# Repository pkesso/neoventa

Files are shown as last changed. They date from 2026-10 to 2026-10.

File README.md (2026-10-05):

# Neoventa — Venta Overdrive PCB

A PCB for the Venta Overdrive, a clone of the PE-12 overdrive by Elektronika. The board is 50 × 54 mm, has 2 layers and fits a Hammond 1590N1 (125B) enclosure. SMD parts go on the bottom side and are assembled by JLCPCB. Pots and the wire pads go on the top side and are soldered by hand.

The schematic and the board are generated by Python scripts from a single circuit description (`tools/circuit2.py`). The layout was not drawn by hand in KiCad.

## Status

**Done**
- The schematic was traced from the stripboard layout and checked against the factory schematic of the PE-12 (`pics/moar/1.png`, `2.png`).
- The ngspice simulation gives about ±0.25 V at the output for a 100 mV, 440 Hz input at Volume 50% (see `simulations/`).
- The board is placed and routed by the scripts. The scripts' own DRC (`tools/drc.py`) reports 0 violations.
- The JLCPCB BOM and CPL files are generated (`jlcpcb/`).
- There is a drilling template for the enclosure lid.

**To do**
- Fill the GND zones (press **B** in the PCB editor), then run KiCad's DRC (Inspect → Design Rules Checker).
- Export Gerbers and drill files (File → Fabrication Outputs).
- Check the orientation of the SOIC-8 and the diodes in the JLCPCB assembly preview. The assembly side is **Bottom**.
- Add 3D models for the pots. The footprints in `Venta.pretty/` don't have any yet.

## Repository layout

```
venta_overdrive.kicad_pro     KiCad project
venta_overdrive.kicad_sch     Schematic (generated by tools/gen_sch2.py)
venta_overdrive.kicad_pcb     Board (generated by tools/write_pcb.py)
Venta.kicad_sym               Project symbol library
Venta.pretty/                 Project footprints: Alpha 16 mm RA pots (single/dual), wire pad
fp-lib-table, sym-lib-table   Library tables (paths relative to ${KIPRJMOD})
jlcpcb/                       BOM_JLCPCB.csv, CPL_JLCPCB.csv for JLCPCB assembly
simulations/                  venta.lib (SPICE models), simulate.py and the plots it generates
drill_template_1590N1.pdf     Lid drilling template, print at 100 % scale (generated by tools/drill_template.py)
tools/                        Python scripts that generate the schematic and the board
requirements.txt              Python dependencies for tools/
```

## Hardware

- **Enclosure:** Hammond 1590N1 (66.5 × 122 × 39.5 mm).
- **Knobs:** 2 × 2. Volume and Drive on top, Eq and Resonance below. IN/OUT jacks on the sides, power on the top.
- **Pots:** Alpha 16 mm, right-angle PCB mount ("41" terminals), B50k: RV16AF-41 single, RV16A01F-41 dual for Eq. The footprints follow the [Alpha datasheet](https://cdn-blog.adafruit.com/uploads/2022/01/Taiwan-Alpha-16mm-pots-datasheet.pdf) (pages 43–45): body Ø17, pin rows 16 mm (and 11 mm on the dual) from the shaft, 5 mm pitch.
- **Board height:** the board sits **12 mm** behind the pots' mounting surface (the inside of the lid, where the bushings rest). The dual pot body is 11.5 mm deep (singles 9.1 mm), and the pins are long enough for up to about 13 mm, so all four bushings are flush with the lid only in the 11.5–13 mm window.
- **Op-amps:** 4558 (JRC4558D, LCSC C443686).
- **Footswitch:** 3PDT, wired to the board.
- **Status LED:** external, with its own resistor. Anode to J6 (LED+), cathode to a 3PDT lug; the common of that 3PDT pole goes to J7 (GND), so the LED lights when the effect is on.
- **Wire pads:** J1 IN, J2 OUT, J3 +9V, J4/J5 GND, J6 LED+ (VCC, to the LED anode), J7 GND (to the 3PDT LED pole).

### Power: DC jack or 9 V battery

The board takes power from J3 (+9V) and J4 (GND) and does not care where it comes from. Switching between a 9 V adapter
and a 9 V (PP3) battery is done off the board, with two switching jacks:

- a 2.1 mm DC jack with a switch lug that is connected to the jack's + contact only while no plug is inserted;
- a stereo (TRS) input jack: its ring lug works as the battery switch.

```
battery +        -> DC jack switch lug
DC jack +        -> J3 (+9V)        (Boss-style adapter: centre negative, sleeve positive)
DC jack -        -> J4 (GND)
battery -        -> input jack ring (R)
input jack sleeve (S) -> J5 (GND)
input jack tip (T)    -> 3PDT -> J1 (IN)
```

- Without an adapter, the battery + reaches J3 through the DC jack's switch lug. Plugging the adapter in opens the switch
  lug, so the battery is disconnected and the pedal runs from the adapter.
- A mono guitar cable in the input jack shorts the ring to the sleeve and connects the battery -. Unplugging the cable
  turns the battery off, so the pedal must not be left with a cable plugged in.
- D3 (SS14) protects against reverse polarity for both sources and drops about 0.3–0.4 V.
- Current draw is about 8–12 mA for the three 4558s plus the status LED (2–10 mA depending on its resistor). An
  alkaline PP3 (~500 mAh) lasts roughly 25–50 hours; a dimmer LED (1–2 mA) noticeably extends that.
- The circuit keeps working down to about 6–7 V, but the op-amps start to clip earlier as the battery runs down.
- Space: a PP3 is 48.5 × 26.5 × 17.5 mm and the free depth under the board in the 1590N1 is only about 20 mm, so check
  the battery's place against the footswitch and jacks before drilling.

### Changes from the original circuit
- R8 (filter summer input) is 75 kΩ as in the factory schematic; the stripboard layout has 15 kΩ, which makes the pedal about 13 dB louder with a weaker resonance peak.
- Resonance (RV2) is wired so that turning it clockwise increases the resonance, as on the original; the stripboard layout has it reversed.
- 1N5817 → SS14, 47 µF → 22 µF ceramic, 1.5 MΩ → 1 MΩ (input pull-down).
- Added 3 × 100 nF supply decoupling caps for the op-amps.
- 1.5 nF filter caps are C0G (NP0).

## Simulation

The schematic contains SPICE fields (`Sim.*`) that point to `simulations/venta.lib`. The library has behavioural models of the op-amp, the diodes and the pots. To run a simulation in KiCad, open Inspect → Simulator. The analysis is taken from the `.tran` text on the schematic. Pot positions are set in the `Sim.Params` field of RV1..RV4 (`POS = 0..1`). V1/V2 are simulation-only sources.

The plots in `simulations/` are generated by `simulate.py`:

```bash
.venv/Scripts/python simulations/simulate.py
```

It builds the netlist from `tools/circuit2.py` and runs ngspice as a shared library: the `ngspice.dll` that ships with KiCad 10, found through `KICAD_BIN` (see Tools).

- `sim_frequency.png` — small-signal frequency response for the Eq and Resonance knobs at 0/50/100 %.
- `sim_waveforms.png` — 440 Hz, 100 mV input and the output at Drive 10/50/100 %.

`render_wav.py` runs a recording through the simulated pedal and writes the result to a WAV file:

```bash
.venv/Scripts/python simulations/render_wav.py riff.wav riff_out.wav --drive 80 --eq 30 --res 70 --volume 60
```

- The input should be a dry (DI) guitar recording; the first channel is used. Its peak is scaled to `--peak` volts
  (default 0.2 V, a single coil; humbuckers give more).
- Knobs are in percent, 0–100 (default 50). `--start` and `--duration` cut a fragment, in seconds.
- `--pickup` drives the input through a single-coil pickup and cable model instead of an ideal source.
- The output is 16-bit PCM at the input's sample rate, normalised to −1 dBFS; `--gain` sets a fixed scale instead
  (dBFS per volt), so different settings can be compared by level.
- It runs at roughly real time (about a minute of computation per minute of audio). The op-amp and diode models in
  `venta.lib` are behavioural, so this shows the character of the circuit rather than an exact copy of a real pedal.

## Tools

Python 3 with numpy, scipy and matplotlib:

```bash
python -m venv .venv
.venv/Scripts/pip install -r requirements.txt
```

`gen_sch2.py` and `write_pcb.py` also need KiCad 10: after writing the files they resave them in the KiCad 10 format with `kicad-cli ... upgrade`. The scripts, `tools/check.py` and `simulations/simulate.py` look for KiCad's bin directory (`kicad-cli`, `ngspice.dll`) in this order: the `KICAD_BIN` environment variable, the directory of `kicad-cli` on `PATH`, then the default install `%ProgramFiles%\KiCad\10.0\bin`. With a standard KiCad 10 install on Windows nothing needs to be set.

`tools/verify2.py` also needs the standalone [ngspice](https://ngspice.sourceforge.io) program. It runs ngspice as a separate program, so it can't use KiCad's `ngspice.dll` the way `simulations/simulate.py` does.

Scripts are run from the `tools/` directory. The pipeline:

| Step | Script | Input → output |
|---|---|---|
| Circuit | `circuit2.py` | Single source of truth: parts, nets, footprints, board side, LCSC numbers |
| Initial placement | `render.py` | → `placed.json`, `placement.png` |
| Placement optimisation | `anneal.py` | `placed.json` → `placed2.json` |
| Routing | `run_route.py` (uses `route.py`) | `placed2.json` → `routed.pkl`, `routed.png` |
| DRC | `drc.py` | `routed.pkl` → report |
| Schematic | `gen_sch2.py` | → `.kicad_sch`, `Venta.kicad_sym`, `sym-lib-table`, `symuuid.json` (and `.kicad_pro` only if it is missing) |
| Board | `write_pcb.py` | `routed.pkl`, `symuuid.json` → `.kicad_pcb`, `Venta.pretty/`, `fp-lib-table` |
| Check | `verify2.py <file.kicad_sch>` | Rebuilds connectivity from the schematic, compares it with `circuit2.py`, runs ngspice |
| Drilling template | `drill_template.py` | Hole positions from `place.py` → `../drill_template_1590N1.pdf` (A4, 1:1) |

Helper modules: `check.py` (repository checks, see below), `place.py` (board outline, placement), `route.py` (2-layer A* grid router, 0.25 mm grid; turns cost extra, so tracks run straight with 45° bends), `pcb_core.py` (footprint loading and geometry, reads `tools/fplib/`: copies of the KiCad 10 library footprints used on the board, so the output does not depend on the installed library version), `kicad_cli.py` (runs `kicad-cli upgrade`), `k10fmt.py` (KiCad 10 library formatter, no longer used by the pipeline).

Notes:
- `routed.pkl` is in `.gitignore`. Without it, `write_pcb.py` can only run after routing again.
- `gen_sch2.py` and `write_pcb.py` overwrite the KiCad files. Changes made by hand in KiCad will be lost if you regenerate them.
- The generators are deterministic: running them again on unchanged inputs reproduces the committed files byte for byte.
- `write_pcb.py` copies library footprints whole from `tools/fplib/` and places the silkscreen labels (1.0 mm text) where they clear pads, other silkscreen and the board edge.

## Checks

`tools/check.py` validates the repository. It needs only the Python standard library and `kicad-cli`.

| Check | What it verifies |
|---|---|
| `format` | KiCad files are in KiCad 10 format |
| `paths` | No absolute paths in KiCad files and library tables |
| `english` | No Cyrillic text in the repository's text files |
| `python` | Python scripts compile |
| `erc` | KiCad ERC reports no errors |
| `drc` | KiCad DRC reports no errors (zones are refilled for the check, the board file is not changed; includes schematic parity) |
| `assembly` | `jlcpcb/` BOM and CPL match the board: parts, values, LCSC numbers, position, side, rotation |

```bash
.venv/Scripts/python tools/check.py
```

Run selected checks by name (`tools/check.py drc assembly`). ERC/DRC warnings are listed but only fail with `--strict`. To accept a DRC/ERC item, exclude it in KiCad (right click → Exclude); excluded items are not reported.

The same script runs as a git pre-commit hook. It runs only the checks relevant to the staged files and blocks the commit if any of them fails. Enable it once per clone:

```bash
git config core.hooksPath .githooks
```

The hook checks the working tree, not the staged versions of the files.

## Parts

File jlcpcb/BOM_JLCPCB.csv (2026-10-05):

Comment | Designator | Footprint | LCSC Part #
22u | C1 | 1206 | C12891
100n | C10,C11,C12 | 0805 | C49678
10u | C2 | 0805 | C15850
22n | C3 | 0805 | C1729
220n | C4,C8,C9 | 0805 | C5378
680n | C5 | 0805 | C107133
1.5n | C6,C7 | 0603 | C107039
1N4148W | D1,D2 | SOD-123 | C81598
SS14 | D3 | SMA | C2480
10k | R1,R2 | 0805 | C17414
3k | R11 | 0805 | C17661
3.3k | R14 | 0805 | C26010
100k | R15 | 0805 | C149504
1M | R3 | 0805 | C17514
220k | R4 | 0805 | C17556
680k | R5 | 0805 | C17797
4.7k | R6 | 0805 | C17673
1k | R7,R16 | 0805 | C17513
15k | R12,R13 | 0805 | C17475
75k | R8 | 0805 | C17819
33k | R9,R10 | 0805 | C17633
JRC4558D | U1,U2,U3 | SOIC-8 | C443686

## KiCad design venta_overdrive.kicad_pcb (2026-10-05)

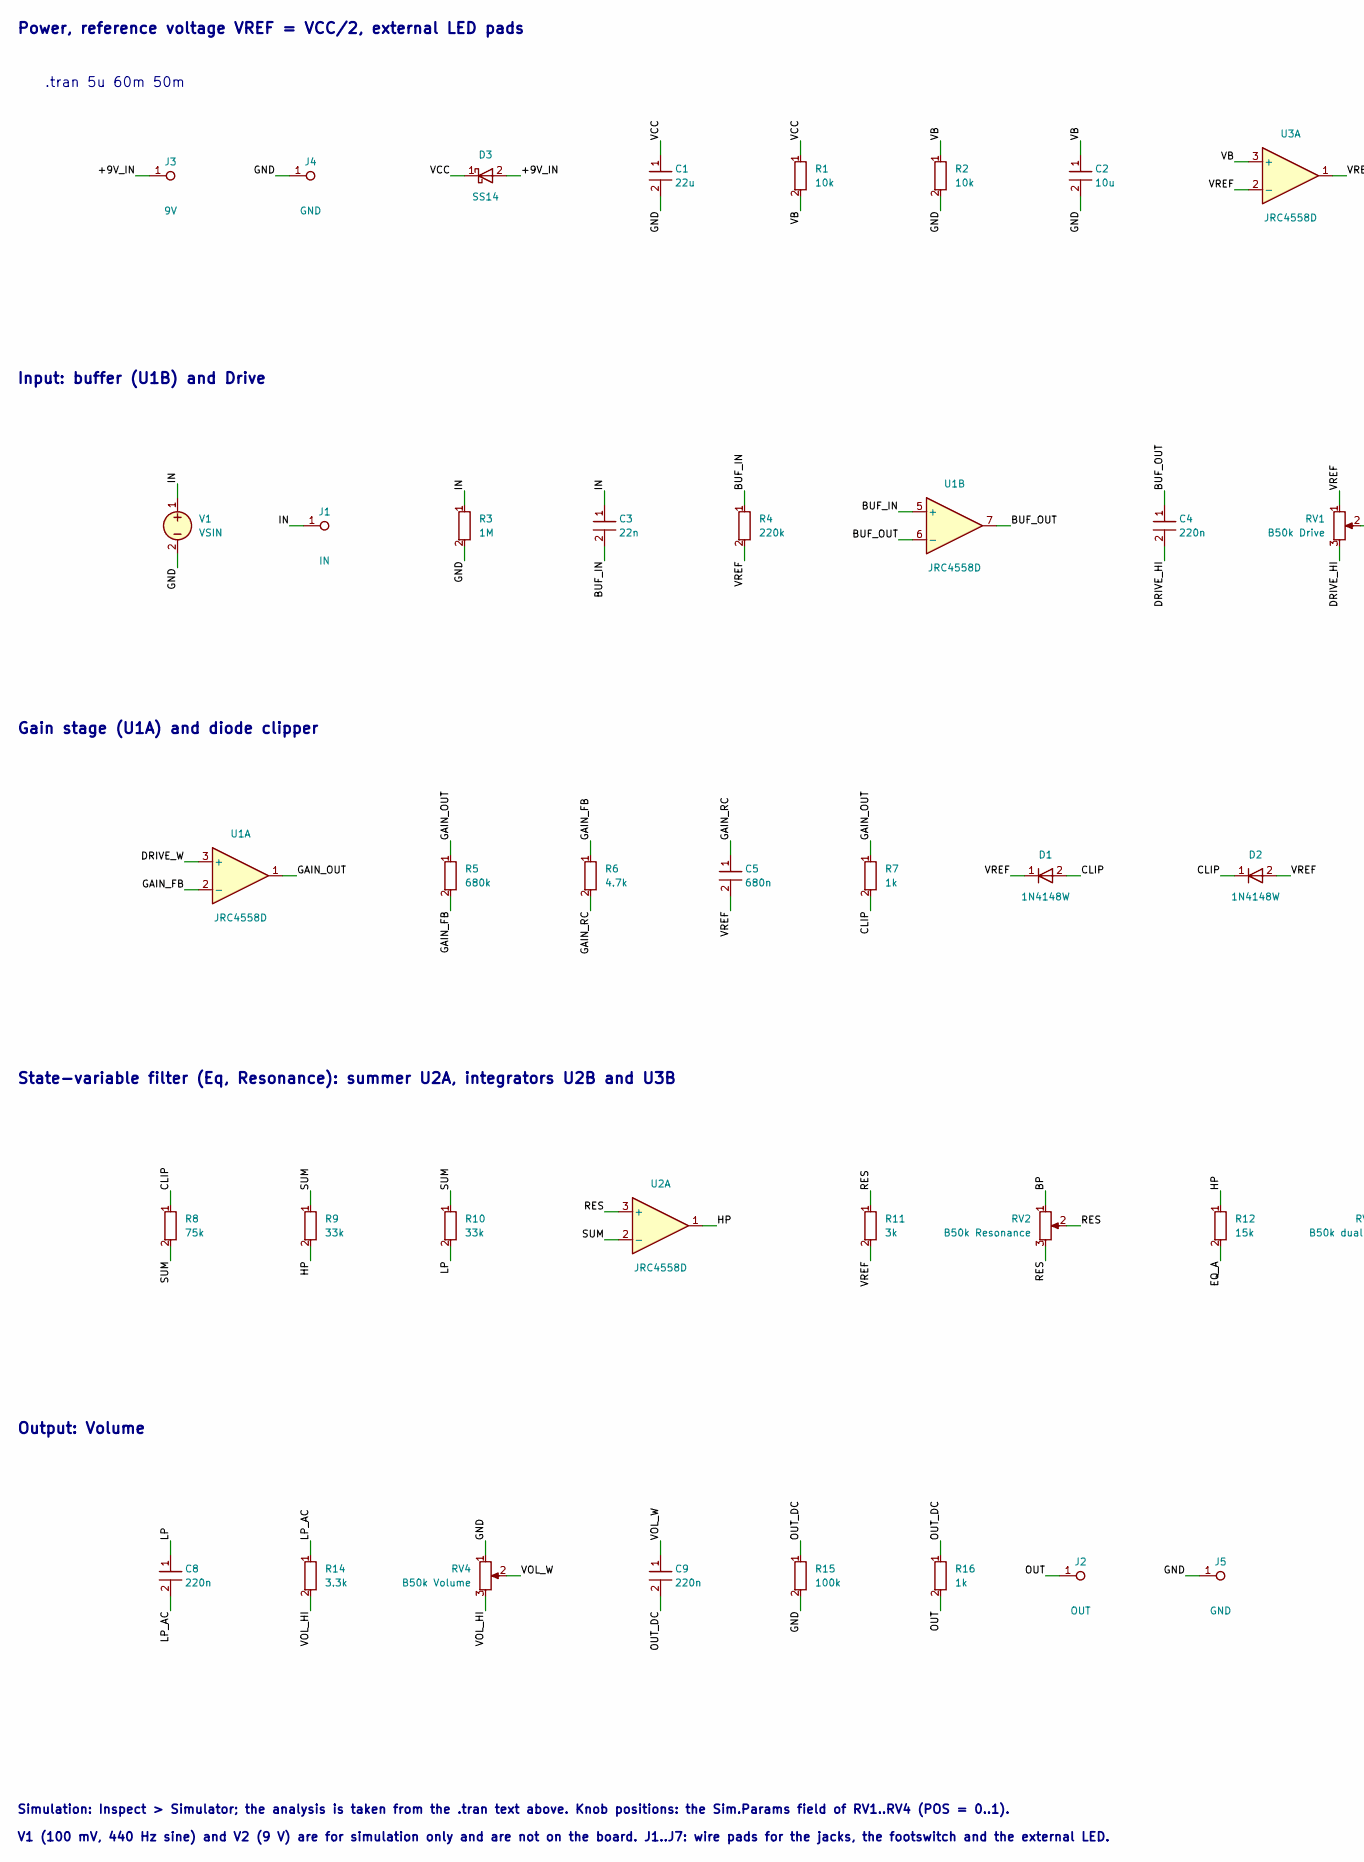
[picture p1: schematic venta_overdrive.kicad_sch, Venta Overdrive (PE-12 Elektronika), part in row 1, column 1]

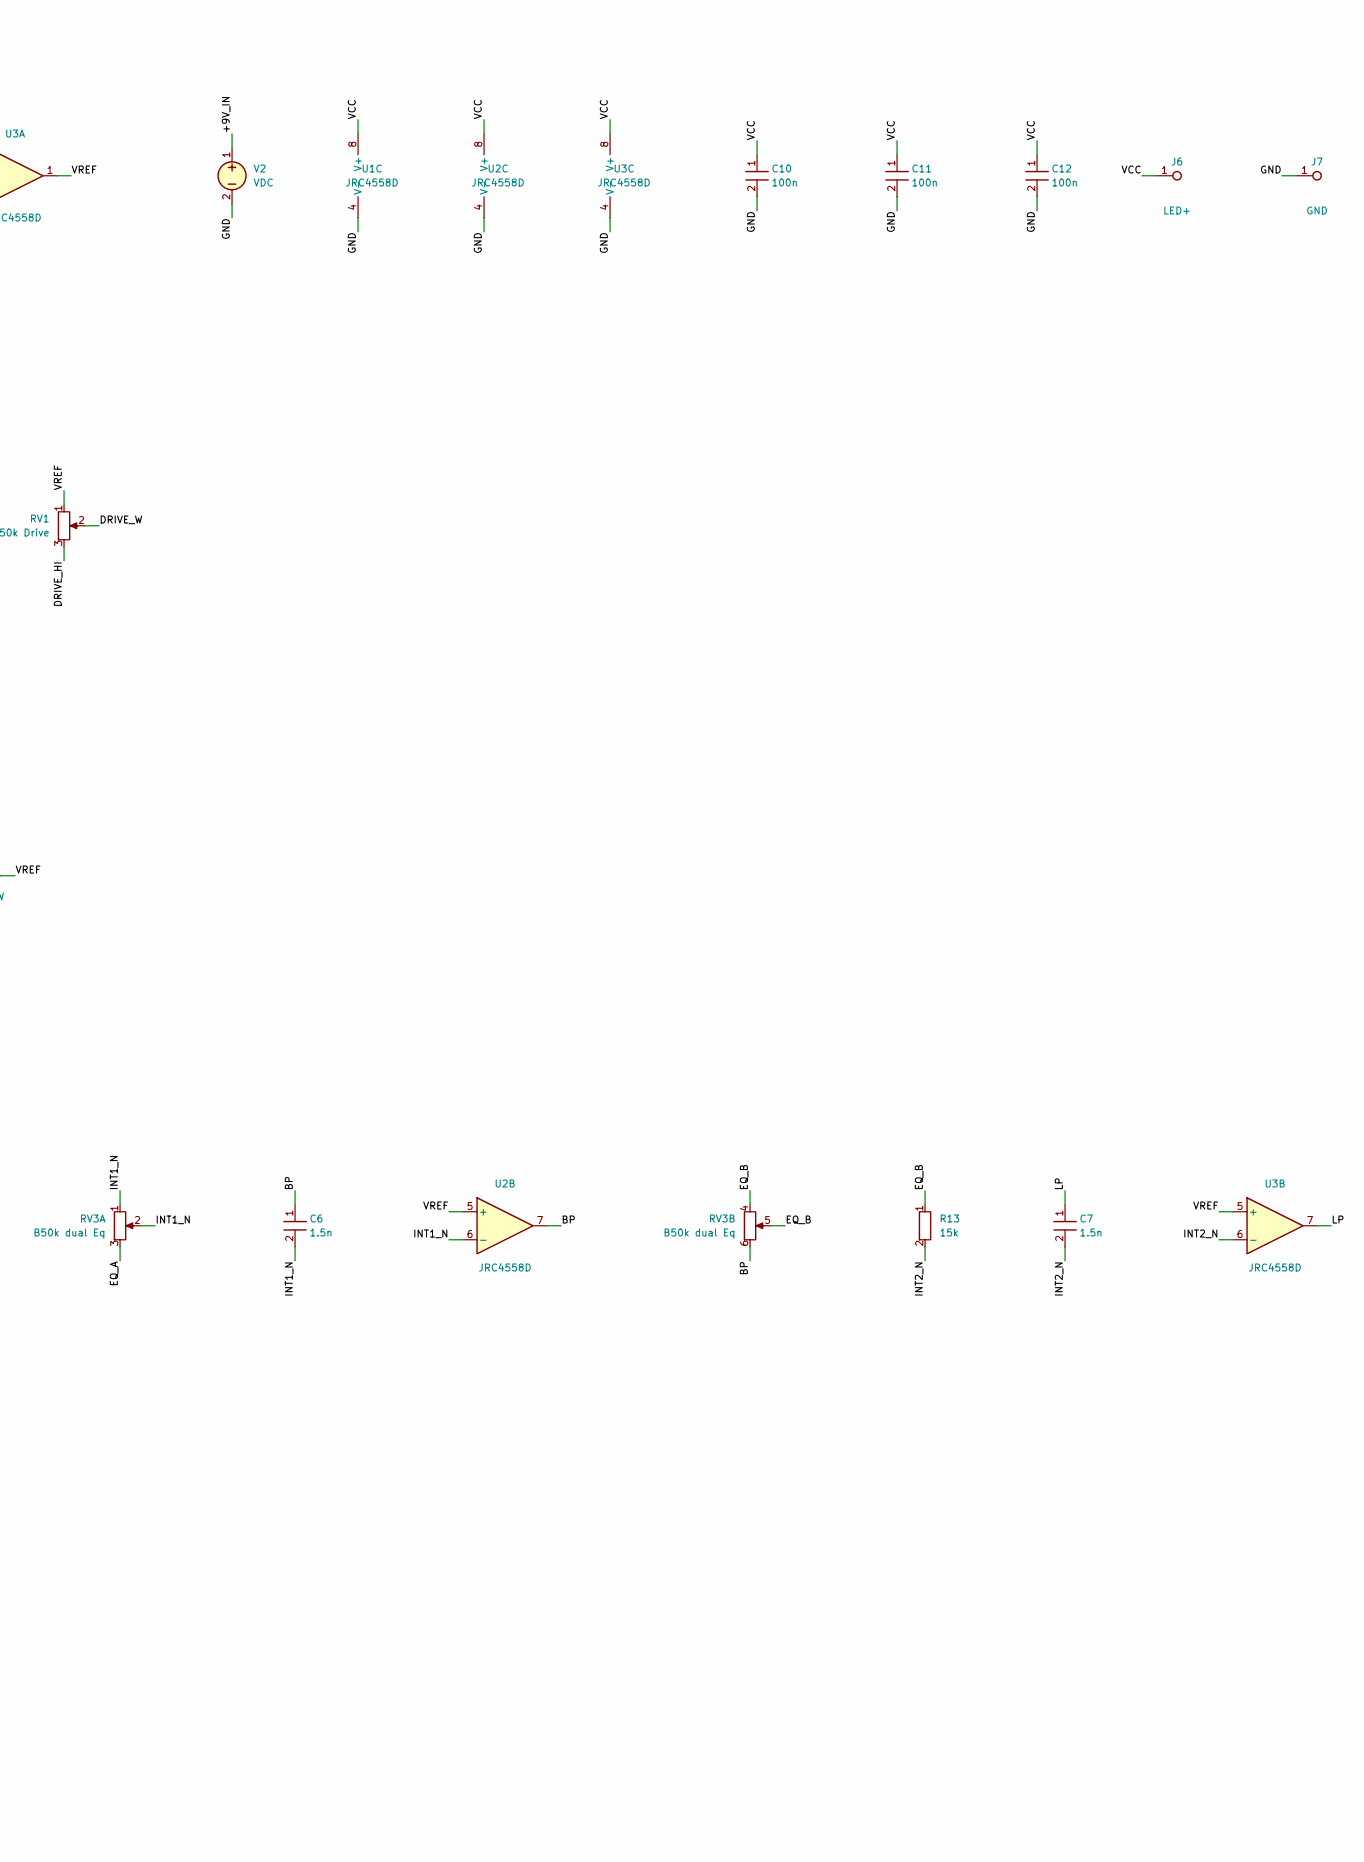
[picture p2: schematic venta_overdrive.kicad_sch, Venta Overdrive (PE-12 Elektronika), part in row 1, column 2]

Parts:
C1: 22u; C_1206_3216Metric; LCSC C12891
C2: 10u; C_0805_2012Metric; LCSC C15850
C3: 22n; C_0805_2012Metric; LCSC C1729
C4, C8, C9: 220n; C_0805_2012Metric; LCSC C5378
C5: 680n; C_0805_2012Metric; LCSC C107133
C6, C7: 1.5n; C_0603_1608Metric; LCSC C107039
C10, C11, C12: 100n; C_0805_2012Metric; LCSC C49678
D1, D2: 1N4148W; D_SOD-123; LCSC C81598
D3: SS14; D_SMA; LCSC C2480
J1: IN; WirePad
J2: OUT; WirePad
J3: 9V; WirePad
J4, J5, J7: GND; WirePad
J6: LED+; WirePad
R1, R2: 10k; R_0805_2012Metric; LCSC C17414
R3: 1M; R_0805_2012Metric; LCSC C17514
R4: 220k; R_0805_2012Metric; LCSC C17556
R5: 680k; R_0805_2012Metric; LCSC C17797
R6: 4.7k; R_0805_2012Metric; LCSC C17673
R7, R16: 1k; R_0805_2012Metric; LCSC C17513
R8: 75k; R_0805_2012Metric; LCSC C17819
R9, R10: 33k; R_0805_2012Metric; LCSC C17633
R11: 3k; R_0805_2012Metric; LCSC C17661
R12, R13: 15k; R_0805_2012Metric; LCSC C17475
R14: 3.3k; R_0805_2012Metric; LCSC C26010
R15: 100k; R_0805_2012Metric; LCSC C149504
RV1: B50k Drive; Pot_Alpha_16mm_RA_Single
RV2: B50k Resonance; Pot_Alpha_16mm_RA_Single
RV3: B50k dual Eq; Pot_Alpha_16mm_RA_Dual
RV4: B50k Volume; Pot_Alpha_16mm_RA_Single
U1, U2, U3: JRC4558D; SOIC-8_3.9x4.9mm_P1.27mm; LCSC C443686
V1: VSIN
V2: VDC

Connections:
/+9V_IN: D3.2 (A), J3.1, V2.1 (+)
/BP: C6.1, RV2.1, RV3.6, U2.7
/BUF_IN: C3.2, R4.1, U1.5 (+)
/BUF_OUT: C4.1, U1.6 (-), U1.7
/CLIP: D1.2 (A), D2.1 (K), R7.2, R8.1
/DRIVE_HI: C4.2, RV1.3
/DRIVE_W: RV1.2, U1.3 (+)
/EQ_A: R12.2, RV3.3
/EQ_B: R13.1, RV3.4, RV3.5
/GAIN_FB: R5.2, R6.1, U1.2 (-)
/GAIN_OUT: R5.1, R7.1, U1.1
/GAIN_RC: C5.1, R6.2
/GND: C1.2, C2.2, C10.2, C11.2, C12.2, J4.1, J5.1, J7.1, R2.2, R3.2, R15.2, RV4.1, U1.4 (V-), U2.4 (V-), U3.4 (V-), V1.2 (-), V2.2 (-)
/HP: R9.2, R12.1, U2.1
/IN: C3.1, J1.1, R3.1, V1.1 (+)
/INT1_N: C6.2, RV3.1, RV3.2, U2.6 (-)
/INT2_N: C7.2, R13.2, U3.6 (-)
/LP: C7.1, C8.1, R10.2, U3.7
/LP_AC: C8.2, R14.1
/OUT: J2.1, R16.2
/OUT_DC: C9.2, R15.1, R16.1
/RES: R11.1, RV2.2, RV2.3, U2.3 (+)
/SUM: R8.2, R9.1, R10.1, U2.2 (-)
/VB: C2.1, R1.2, R2.1, U3.3 (+)
/VCC: C1.1, C10.1, C11.1, C12.1, D3.1 (K), J6.1, R1.1, U1.8 (V+), U2.8 (V+), U3.8 (V+)
/VOL_HI: R14.2, RV4.3
/VOL_W: C9.1, RV4.2
/VREF: C5.2, D1.1 (K), D2.2 (A), R4.2, R11.2, RV1.1, U2.5 (+), U3.1, U3.2 (-), U3.5 (+)

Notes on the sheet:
.tran 5u 60m 50m
Power, reference voltage VREF = VCC/2, external LED pads
Output: Volume
V1 (100 mV, 440 Hz sine) and V2 (9 V) are for simulation only and are not on the board. J1..J7: wire pads for the jacks, the footswitch and the external LED.
Input: buffer (U1B) and Drive
Simulation: Inspect > Simulator; the analysis is taken from the .tran text above. Knob positions: the Sim.Params field of RV1..RV4 (POS = 0..1).
Gain stage (U1A) and diode clipper
State-variable filter (Eq, Resonance): summer U2A, integrators U2B and U3B

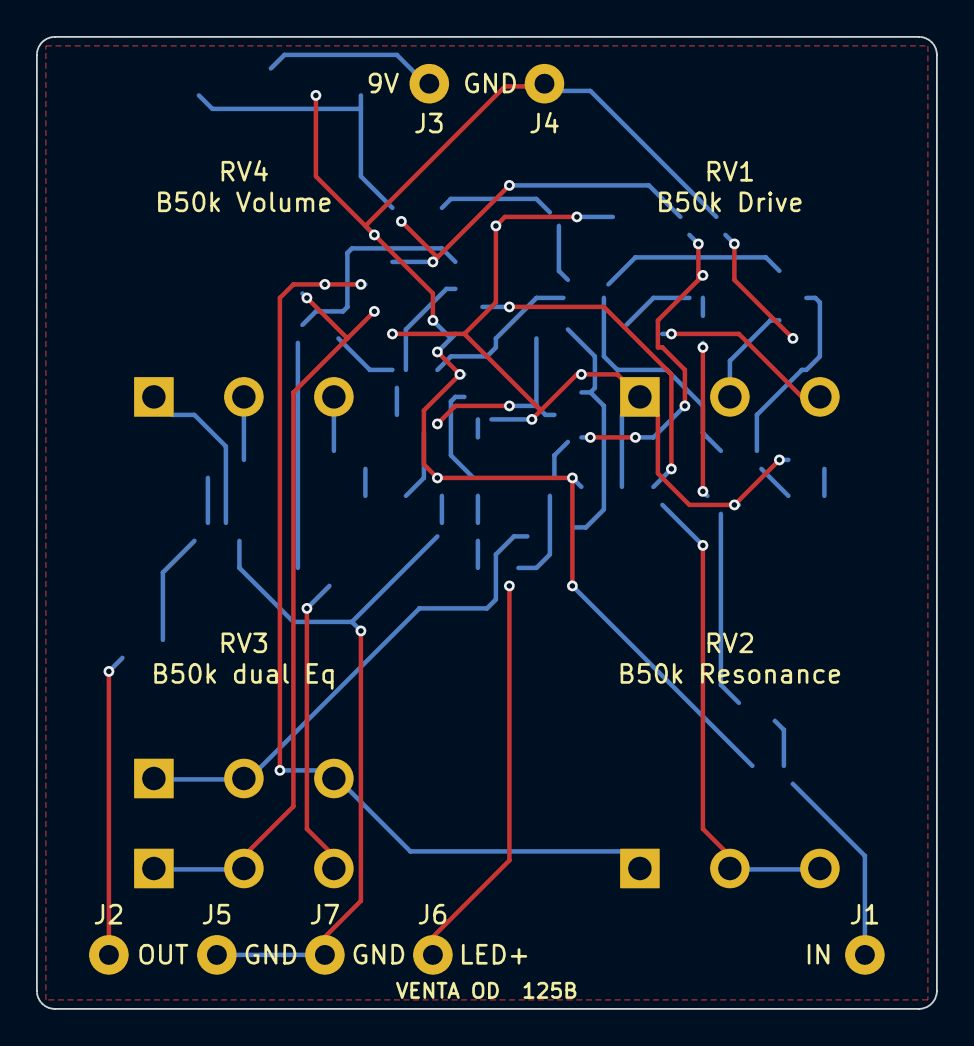
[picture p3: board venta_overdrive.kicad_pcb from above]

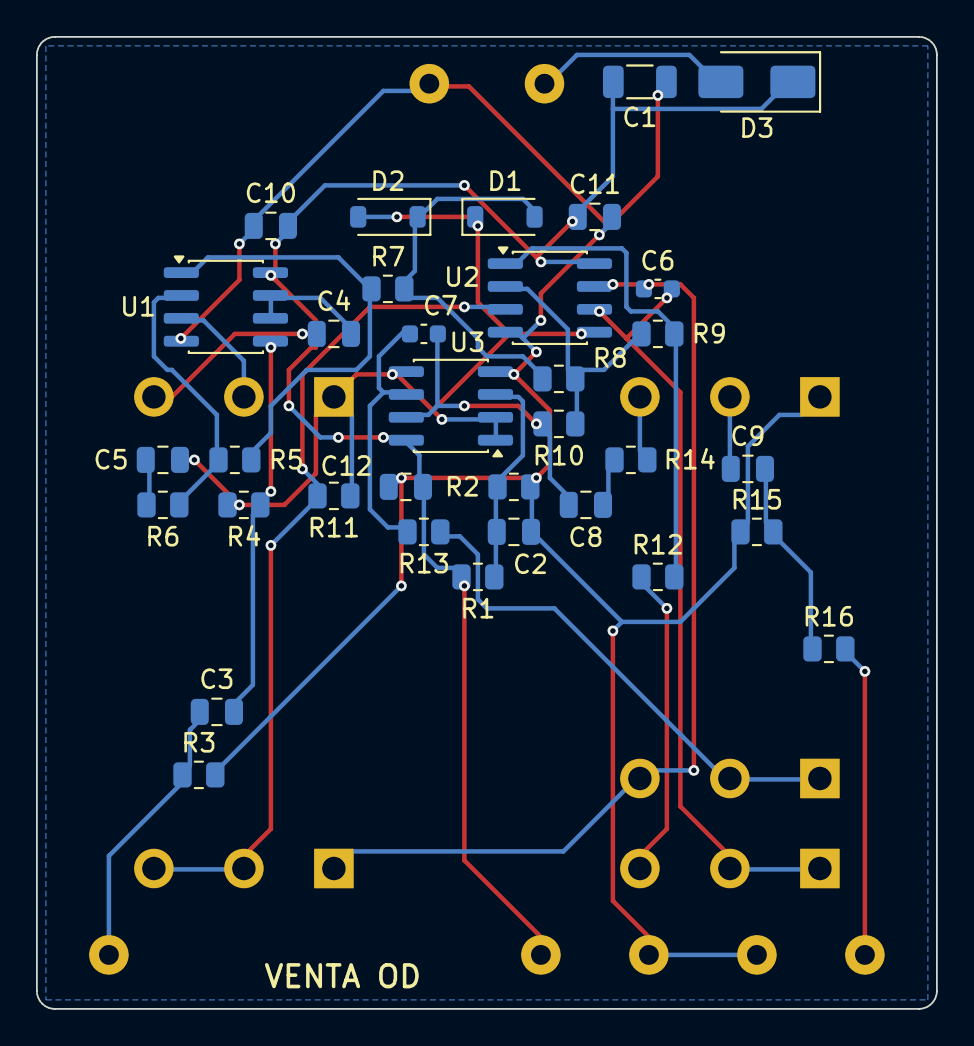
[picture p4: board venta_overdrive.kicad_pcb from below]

Board: 2 copper layers, 50.0 x 54.0 mm, 45 parts (34 on the bottom side), 28 nets.

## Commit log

2026-10-05 first successful board model
    [BOM_JLCPCB.csv, venta_overdrive.kicad_pcb, venta_overdrive.kicad_sch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]
2026-10-05 fix CRLF
    [venta_overdrive.kicad_pcb, venta_overdrive.kicad_sch]
2026-10-05 pcb lint
    [venta_overdrive.kicad_pcb]
2026-10-05 use external LED
    [BOM_JLCPCB.csv, venta_overdrive.kicad_pcb, venta_overdrive.kicad_sch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]
2026-10-05 use external LED - cleanup
    [venta_overdrive.kicad_sch]
2026-10-05 fix R8 nominal
    [BOM_JLCPCB.csv, venta_overdrive.kicad_pcb, venta_overdrive.kicad_sch]
2026-10-05 fix Resonance direction
    [venta_overdrive.kicad_pcb, venta_overdrive.kicad_sch]
2026-10-05 fix huge diffs: genetating UUIDs from component name instead of sequence number
    [venta_overdrive.kicad_pcb, venta_overdrive.kicad_sch]
2026-10-05 improve path to kicad vars
2026-10-05 adjust board for dual-gang pot
    [venta_overdrive.kicad_pcb]
2026-10-05 README.md: add battery connection scheme
2026-10-05 render_wav: simulating effect on sound samples
